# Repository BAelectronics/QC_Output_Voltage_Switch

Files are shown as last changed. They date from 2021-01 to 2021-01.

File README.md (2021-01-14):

[Kapcsolódó videó / Related video](https://youtu.be/jLJ_5dmPatM)

The language of the video is Hungarian, but English subtitles are available.

# USB gyorstöltő kimenő feszültségét beállító eszköz (5/9/12V)
A videóban bemutatott és a projekthez tartozó fájlok, rajzok, kódok stb. megtalálhatóak ezen az oldalon.

A vezérlőpanel kapcsolása és nyákterve KiCad 5.1 programmal készült.

Ezzel a kis adapterrel egyszerűen lehet módosítani egy Quick Charge 2.0 vagy 3.0 képes USB-s gyorstöltő kimenő feszültségét csupán egy ATtiny13A MCU-val és néhány egyéb alkatrésszel. A hardver egyféle, azonban 2 eltérő működésű szoftver van fejlesztve, hogy ha valaki utánépítené akkor ki tudja választani a számára szimpatikus módot. Természetesen lehet kombinálni is vagy másfajta működést kitalálni ha van hozzá affinitásod.

### MODE 1 képességek
- +gomb --> feszültség növelése +0,2Volttal
- -gomb --> feszültség csökkentése -0,2Volttal
- Mindkét gombot egyszerre lenyomva --> 5V beállítás

### MODE 2 képességek
- +gomb --> ugrás 9Voltra 5Voltról vagy 12Voltra 9Voltról
- -gomb --> ugrás 9Voltra 12Voltról vagy 5Voltra 9Voltról
- Egyiket nyomvatartva és megnyomva a másikat --> beállított feszültség mentése EEPROM-ba, következő indításnál magától betöltődik

# USB Quick Charge output voltage switch device (5/9/12V)
You can find here files, schematics, codes, etc. Everything what presented in the video and associated with the project.

The control board schematic and PCB designed with KiCad 5.1.

With this small adapter, you can easily adjust the output voltage of a Quick Charge 2.0 or 3.0 capable USB charger with only an ATtiny13A MCU and few parts. The hardware is one, but the software has 2 different mode, so if you want to rebuild, then you can choose the mode they like. Of course, you can also combine or develop new with a different kind of action if you have an affinity for it.

### MODE 1 features
- +button --> increase the Voltage +0,2V
- -button --> decrease the Voltage -0,2V
- Both button pressed at the same time --> set 5V

### MODE 2 features
- +button --> jump to 9V from 5V or jump to 12V from 9V
- -button --> jump to 9V from 12V or jump to 5V from 9V
- One button hold and press the other --> save set Voltage to the EEPROM (next start auto load)

The device:

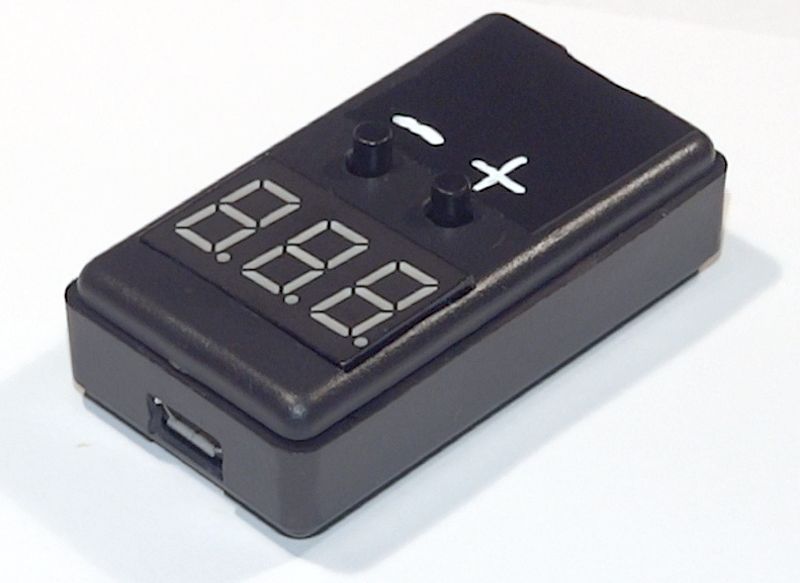
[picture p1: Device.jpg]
device


Thanks to them:
- [Hugatry's HackVlog](https://www.youtube.com/channel/UCHgeChD442K0ah-KxEg0PHw) He came up with the idea and first code to control QC2. 
- [QC2Control](https://github.com/septillion-git/QC2Control) Timo Engelgeer (Septillion) who made a nice wrapper for QC2.
- [QC3Control](https://github.com/vdeconinck/QC3Control) He is the latest developer of the idea for QC3.

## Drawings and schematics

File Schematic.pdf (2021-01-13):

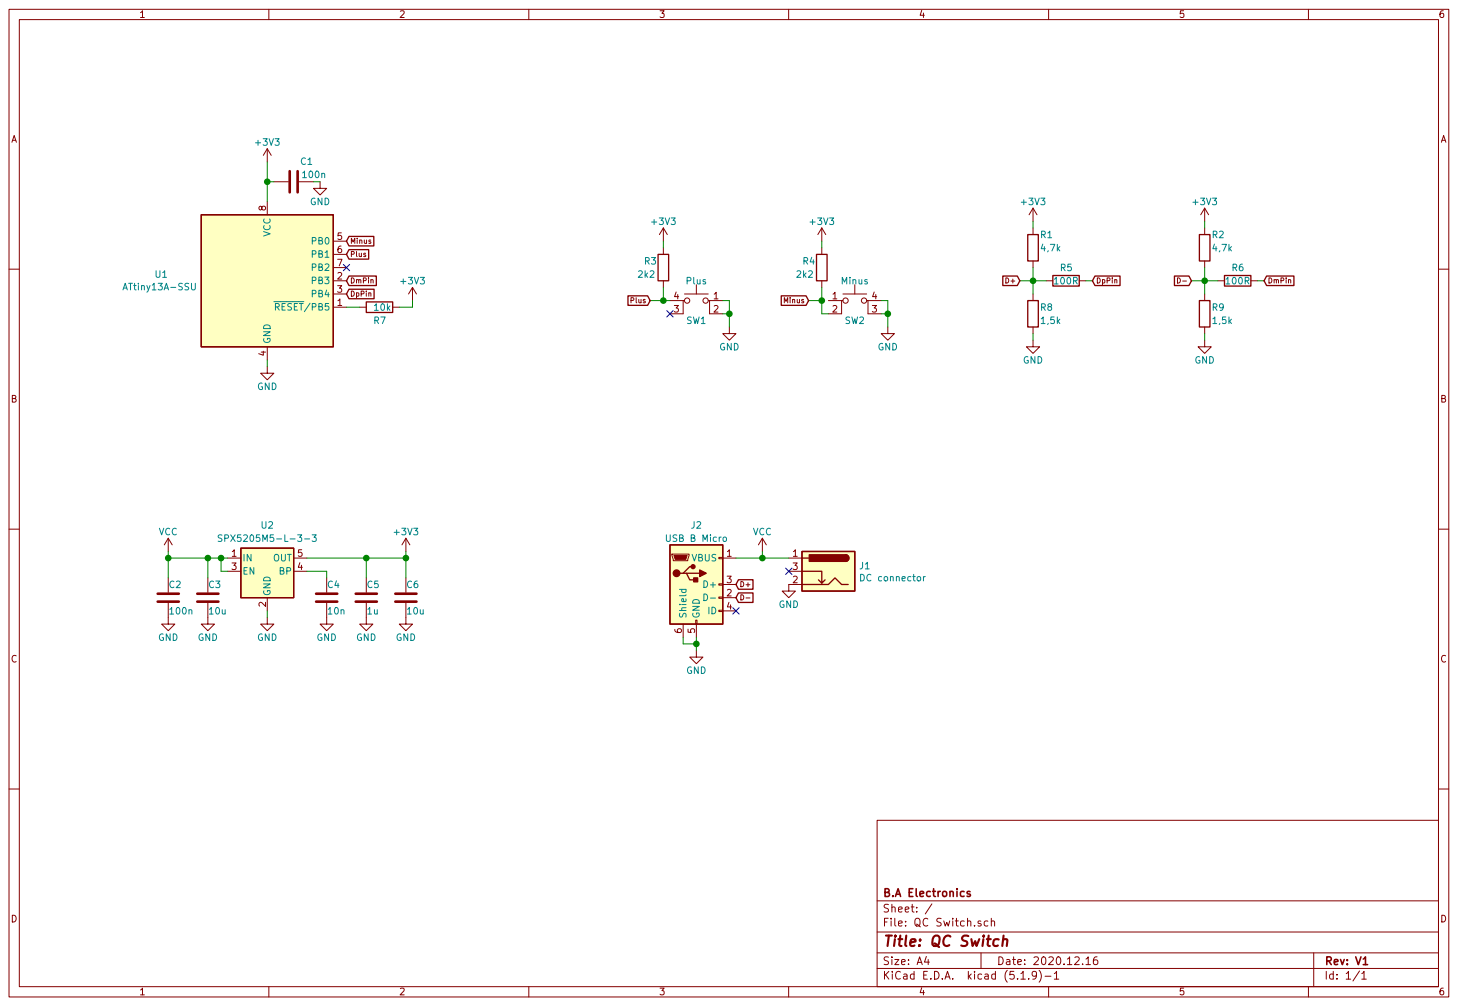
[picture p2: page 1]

2 EN 3 BP 4 OUT 5 U2 SPX5205M5-L-3-3 GND GND GND GND

File: QC Switch.sch Sheet: / B.A Electronics C3

Id: 1/1 Title: QC Switch

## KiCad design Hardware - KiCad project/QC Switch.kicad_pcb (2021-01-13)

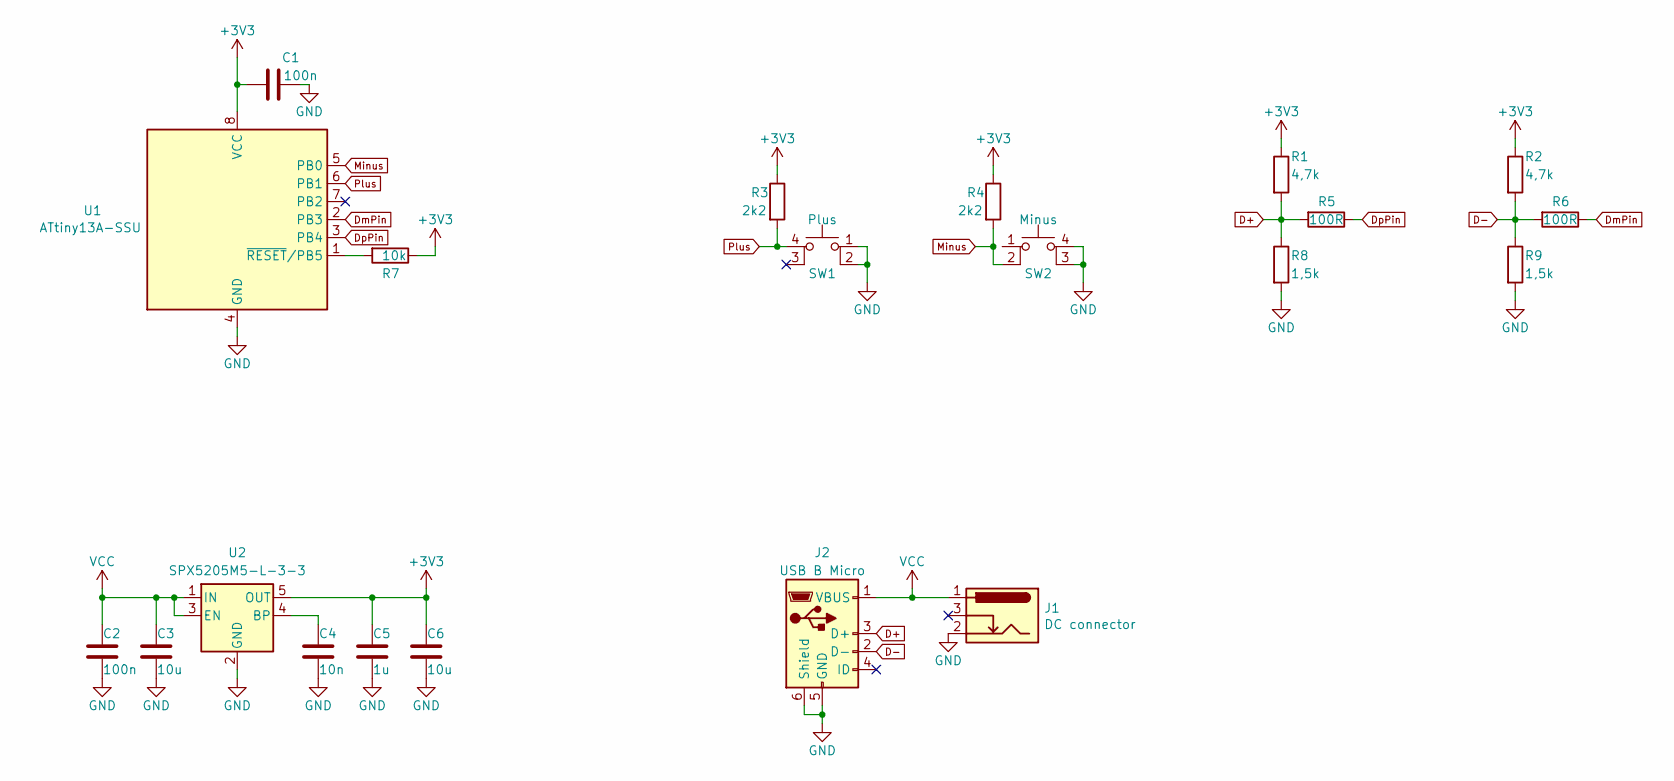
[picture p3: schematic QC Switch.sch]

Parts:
C1, C2: 100n; C_0805_2012Metric
C3, C6: 10u; C_0805_2012Metric
C4: 10n; C_0805_2012Metric
C5: 1u; C_0805_2012Metric
J1: DC connector; BarrelJack_Horizontal
J2: USB B Micro; USB_Micro-B_Amphenol_10104110_Horizontal
R1, R2: 4,7k; R_0805_2012Metric
R3, R4: 2k2; R_0805_2012Metric
R5, R6: 100R; R_0805_2012Metric
R7: 10k; R_0805_2012Metric
R8, R9: 1,5k; R_0805_2012Metric
SW1: Plus; SW_TH_Tactile_Omron_B3F-10xx
SW2: Minus; SW_TH_Tactile_Omron_B3F-10xx
U1: ATtiny13A-SSU; SOIC-8_3.9x4.9mm_P1.27mm
U2: SPX5205M5-L-3-3; SOT-23-5

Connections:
+3V3: C1.1, C5.1, C6.1, R1.1, R2.1, R3.1, R4.1, R7.1, U1.8 (VCC), U2.5 (OUT)
D+: J2.3 (D+), R1.2, R5.2, R8.1
D-: J2.2 (D-), R2.2, R6.2, R9.1
DmPin: R6.1, U1.2 (PB3)
DpPin: R5.1, U1.3 (PB4)
GND: C1.2, C2.2, C3.2, C4.2, C5.2, C6.2, J1.2, J2.5 (GND), J2.6 (Shield), R8.2, R9.2, SW1.1, SW1.2, SW2.3 (K), SW2.4 (A), U1.4 (GND), U2.2 (GND)
Minus: R4.2, SW2.2, U1.5 (PB0)
unnamed: C4.1, U2.4 (BP)
unnamed: R7.2, U1.1 (~RESET~/PB5)
Plus: R3.2, SW1.4 (A), U1.6 (PB1)
VCC: C2.1, C3.1, J1.1, J2.1 (VBUS), U2.1 (IN), U2.3 (EN)

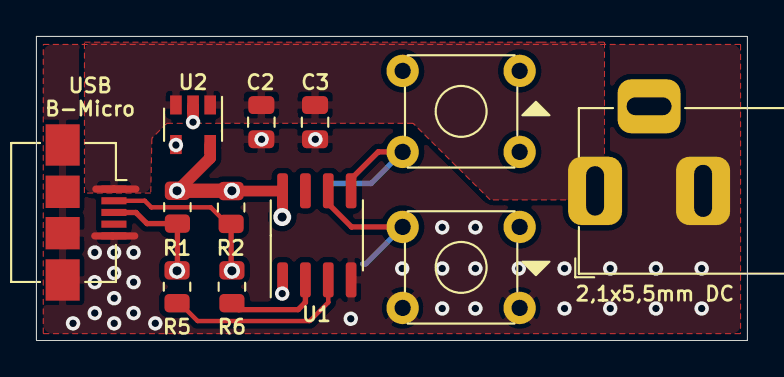
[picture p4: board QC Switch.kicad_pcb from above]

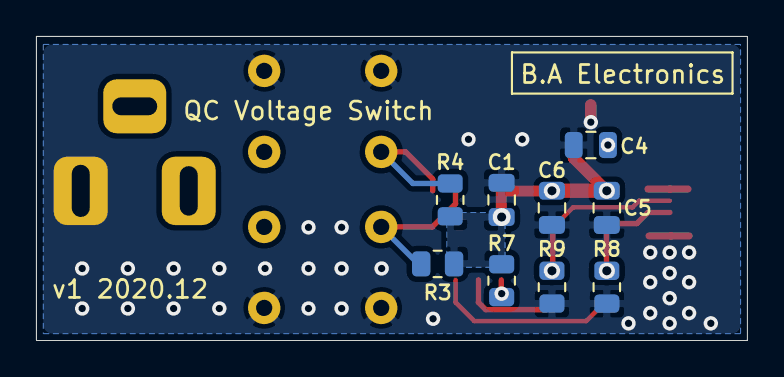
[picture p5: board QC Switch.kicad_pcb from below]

Board: 2 copper layers, 39.5 x 16.9 mm, 21 parts (9 on the bottom side), 11 nets.

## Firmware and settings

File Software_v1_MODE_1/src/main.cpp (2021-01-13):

/* QC Charger Voltage Switcher
*  v1 2020.12.30
*
*  ---> MODE 1 <---
*  
*  Behavior:
*   + button --> increase the Voltage +0,2V
*   - button --> decrease the Voltage -0,2V
*   Both button pressed at the same time --> set 5V
*
*  PlatformIO configuration changed for MicroCore (platformio.ini) :
*    Main frequency 1,2MHz --> board_build.f_cpu = 1200000L
*  Apply fuses: "pio run -e set_fuses -t fuses" command
*
*  Actual used programmer: USBasp
*/


// Includes ----------------------------------------------------------------------
#include <QC3Control.h>

// Constants ---------------------------------------------------------------------
#define plus_button        1
#define minus_button       0
#define prell_time         100

// Variables ---------------------------------------------------------------------
unsigned long prevMillis = 0;
unsigned long actMillis = 0;

// Library setting ---------------------------------------------------------------
QC3Control quickCharge(4, 3);
//                     +  -

// Init --------------------------------------------------------------------------
void setup()
{
    pinMode(minus_button, INPUT);
    pinMode(plus_button, INPUT);
    delay(200);
}

// Main program ------------------------------------------------------------------
void loop()
{
    if (!(digitalRead(plus_button)))
    {
        if ((digitalRead(minus_button)))
        {
            actMillis = millis();
            if (actMillis - prevMillis >= prell_time) quickCharge.incrementVoltage();
            prevMillis = actMillis;
        }
    }

    if (!(digitalRead(minus_button)))
    {
        if ((digitalRead(plus_button)))
        {
            actMillis = millis();
            if (actMillis - prevMillis >= prell_time) quickCharge.decrementVoltage();
            prevMillis = actMillis;
        }
        else
        {
            quickCharge.set5V();
            delay(200);
        }
    }
}

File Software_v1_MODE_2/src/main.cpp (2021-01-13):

/* QC Charger Voltage Switcher
*  v1 2020.12.30
*
*  ---> MODE 2 <---
*  
*  Behavior:
*   + button --> jump to 9V from 5V or jump to 12V from 9V
*   - button --> jump to 9V from 12V or jump to 5V from 9V
*   One button hold and press the other --> save set Voltage to the EEPROM (next start auto load)
*
*  PlatformIO configuration changed for MicroCore (platformio.ini) :
*    Main frequency 1,2MHz --> board_build.f_cpu = 1200000L
*  Apply fuses: "pio run -e set_fuses -t fuses" command
*
*  Actual used programmer: USBasp
*/


/* !!! Attention !!!
*  At the first programming, we have to rewrite the memory junk where want to store the last set Voltage
*  Instructions:
*  - Remove slashes at the following define before first programming
*  - Upload the code
*  - Add comment slashes again
*  - Upload the code
*  - Ready for use
*/

//#define FIRST_PROGRAMMING


// Includes ----------------------------------------------------------------------
#include <QC3Control.h>
#include <EEPROM.h>

// Constants ---------------------------------------------------------------------
#define plus_button        1
#define minus_button       0
#define prell_time         100

// Variables ---------------------------------------------------------------------
byte state = 0;
byte set = 1;
unsigned long prevMillis = 0;
unsigned long actMillis = 0;

// Library setting ---------------------------------------------------------------
QC3Control quickCharge(4, 3);
//                     +  -

// Init --------------------------------------------------------------------------
void setup()
{
    pinMode(minus_button, INPUT);
    pinMode(plus_button, INPUT);
    
    #ifdef FIRST_PROGRAMMING
    EEPROM.write(1, state);
    while(1);  
    #endif                   

    state = EEPROM.read(1);
    delay(200);
}

// Main program ------------------------------------------------------------------
void loop()
{
    if (!(digitalRead(plus_button)))
    {
        if ((digitalRead(minus_button)))
        {
            actMillis = millis();
            if (actMillis - prevMillis >= prell_time)
            {
                if (state < 2) 
                {
                    state++;
                    set = 1;
                }
            }
            prevMillis = actMillis;
        }
    }

    if (!(digitalRead(minus_button)))
    {
        if ((digitalRead(plus_button)))
        {
            actMillis = millis();
            if (actMillis - prevMillis >= prell_time) 
            {
                if (state > 0) 
                {
                    state--;
                    set = 1;
                }
            }
            prevMillis = actMillis;
        }
        else
        {
            EEPROM.write(1, state);
            delay(500);
        }
        
    }

    if (set)
    {
        if (state == 0) quickCharge.set5V();
        if (state == 1) quickCharge.set9V();
        if (state == 2) quickCharge.set12V();
        set = 0;
    }
}
